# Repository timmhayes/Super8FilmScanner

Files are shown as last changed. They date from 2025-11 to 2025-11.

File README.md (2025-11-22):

# 3D printed Super 8 Film Scanner (Pi 5 / Ender 3 Fork)

> **NOTE:** This is a forked version of the excellent repo provided by Stuart Pittaway at [stuartpittaway/Super8FilmScanner](https://github.com/stuartpittaway/Super8FilmScanner). 
>
> I initially planned to make a few minor changes and update his repo via a pull request, but I've completely rewritten much of the code and I'm not sure that is possible now. In addition, many of the changes were made quickly with LLM coding tools and the code needs additional testing. 

**Substantial changes in this fork:**
1.  **Raspberry Pi 5 Support:** Updated to run on [Raspberry Pi 5](https://www.raspberrypi.com/products/raspberry-pi-5/) using the latest Pi OS (Bookworm/Trixie). The code now supports `picamera2` rather than relying on the deprecated `picamera`.
2.  **Machine Learning Alignment:** Improved sprocket alignment using a custom-trained [YOLO](https://docs.ultralytics.com/) machine learning model for object detection. (Moved to a separate repo).
3.  **Ender 3 Hardware:** Documented how an old [Ender 3](https://www.creality.com/products/ender-3-3d-printer) can be used to provide most of the moving parts. My build was created using an Ender 3 Pro with an updated [Silent Board](https://www.creality3dofficial.com/products/creality-silent-mainboard-v4-2-7). If you don't have one handy, a cheap secondhand model provides the motherboard, stepper motors, a control panel (not needed, but useable here), and some T-slotted rail to use on other projects.

---

# Project Overview

The code and scanner were created quickly to achieve the job of scanning a handful of Super 8 reels at an acceptable quality. The code is unlikely to run straight out of the box on your computer/system; it will need minor amendments to folder names/paths etc.

## Items needed for this project
* [Raspberry Pi 4](https://www.raspberrypi.com/products/raspberry-pi-4-model-b/) or [Raspberry Pi 5](https://www.raspberrypi.com/products/raspberry-pi-5/)
* [Pi Advanced 12megapixel Camera](https://www.raspberrypi.com/products/raspberry-pi-high-quality-camera/)
* [Microscope lens for the Raspberry Pi High Quality Camera - 0.12-1.8x](https://shop.pimoroni.com/products/microscope-lens-0-12-1-8x)
* 3D printed frame (files in this repository). The FreeCAD files are from the original project. STL files have neem added for convenience. A simple manual film rewinder is also included, but to complete the build you'll need to mount it on some T-slot rail and add some V-slot roller wheels for bearings. Both of these can can be pulled from an Ender 3.
* Two small depth stepper motors (NEMA 17 style - can be pulled from an old Ender 3)
* RAMPS style motherboard for controlling the stepper motors and running [MARLIN](https://github.com/MarlinFirmware/Marlin) (can be pulled from an old Ender 3)
* Two stepper drivers (e.g., A4988) - **Not required** if using an Ender 3 motherboard, as the drivers are soldered onto the board.
* ~5000K "cool white" MR16 style LED light bulb (5 Watt). A [base socket](https://www.amazon.com/dp/B073FFBSJM) is also helpful. I used a 12V version and needed a [buck converter](https://www.amazon.com/dp/B076H3XHXP) to step the voltage down from the 24V Ender 3 power supply.
* A small spring. One from [this assortment](https://www.amazon.com/dp/B0F9PZ5QHL) will work.
* A rubber gasket to fit over the stepper motor gear to make contact with the film. One of these [rubber grommets](https://www.amazon.com/dp/B07YXXYY7R) worked, but wasn't perfect and needed modification.
* 24V Power supply (an old Ender 3 PSU will do)
* MicroSD card
* Various M3 screws (like [these](https://www.amazon.com/dp/B07VRC5RJ8)).

# YouTube Video (Original Project)

See Stuart Pittaway's video on how to use and build the *original* device. 
**Note:** The physical build in this fork differs (using Ender 3 parts), but the general concept remains the same.

https://youtu.be/rd1Xu6e6nrw

# Setup

This is a rough setup description and some steps might be missing, but here is what's necessary:

## Step 1 - Flash Marlin to the mainboard
If needed, flash your mainboard with the Marlin Firmware. You can find the latest release [here](https://marlinfw.org/meta/download/). Open Arduino IDE, make the required changes (for your mainboard), connect the Mainboard via USB and upload the firmware.

**Note:** If your motherboard was pulled from an Ender 3, this step is likely unnecessary as it should already be running Marlin.

## Step 2 - Install the Raspberry Pi OS on the Raspberry Pi
Install the Raspberry Pi Imager, which you can find [here](https://www.raspberrypi.com/software/).

Plug the microSD card into your computer and choose to install the **Raspberry Pi OS (64-bit)** (Bookworm or later) in the imager software. Click the gear icon to open the advanced settings. Choose a hostname (e.g., "scanner"), add a username/password, activate SSH under "services", and add your Wifi settings.

## Step 3 - Wiring
Assemble the scanner according to the 3D files.

Mainboard
*Makerbase MKS 3D Printer Control Board*

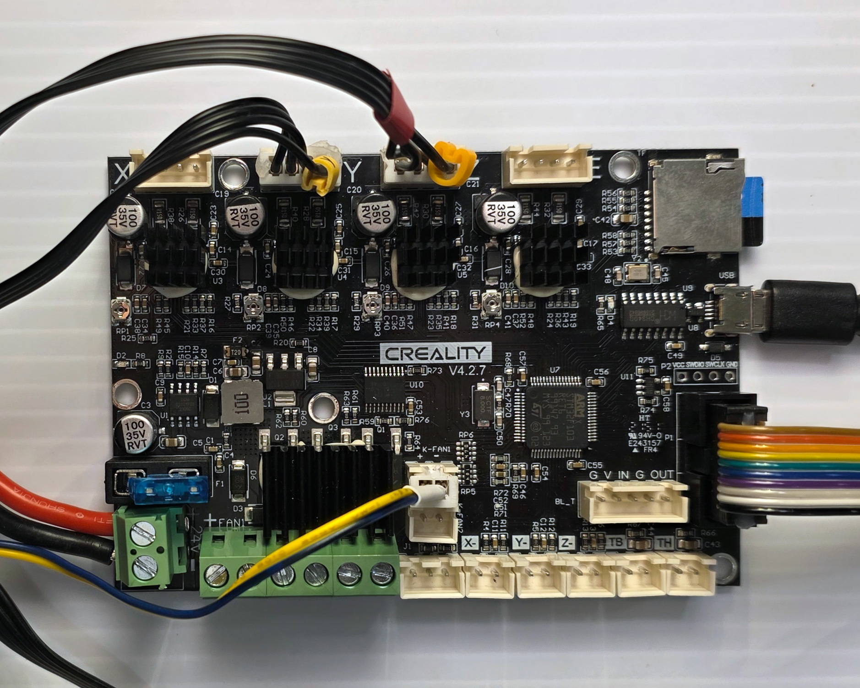
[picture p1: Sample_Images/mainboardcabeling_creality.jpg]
Creality Ender 3 Silent Motherboard

*Creality Ender 3 Silent Motherboard*

1.  Plug the stepper drivers into the mainboard's Y and Z axis (if not integrated), then plug in the stepper motors. 
2.  Consider adding a heatsink to the Y-axis stepper driver, as it is used the most. 
    *   *Tip:* If the Y-Axis stepper from the Ender 3 runs in the wrong direction, you may need to reverse the plug orientation or configure this in Marlin.
3.  Slot the Raspberry Pi HQ camera ribbon cable into the Raspberry Pi and lock it in place.
4.  Plug the LED wires into the fan header.
5.  Connect the power supply to the mainboard via the two cables. **Ensure the power supply is disconnected from the wall while wiring.**
6.  *(Optional)* Connect the Ender 3 control panel. This is not needed but may help with troubleshooting.(See the rainbow colored cable to the right above.)
7.  Connect the mainboard to the Raspberry Pi via USB.

## Step 4 - Connecting to the Raspberry Pi
If you don't plan to use the scanner with a dedicated monitor, keyboard, and mouse, you must connect via Terminal and VNC.

1.  Turn on the Raspberry Pi and the PSU.
2.  Use SSH to connect to `<username>@scanner.local`.
3.  Enable VNC on the Pi:
    1. Run the command: `sudo raspi-config`
    2. Navigate to `Interface Options` (option 5).
    3. Select `VNC` (option P3).
    4. Choose `Yes` to enable VNC.
    5. Exit raspi-config. RealVNC Server will start automatically on boot.
4. Download and install a VNC client on the computer you will connect to your Raspberry Pi. (e.g. [RealVNC Viewer](https://www.realvnc.com/en/connect/download/viewer/))

## Step 5 - Install dependencies
The software relies on `picamera2`, `pyserial`, and `opencv`. The first two should be available in the default system build, so start by installing OpenCV:

```bash
sudo apt update
sudo apt upgrade
sudo apt install python3-opencv
```

If you are running an older version of the Raspberry Pi OS and need the additional libraries, install them:
```bash
sudo apt install python3-picamera2 python3-serial
```

The following is not required, but you might find the [Visual Studio Code](https://code.visualstudio.com/) IDE helpful:
```bash
sudo apt install code
```

# Scanning Process

## Step 1 - Capture full frame masters

On the Raspberry Pi, use the python code in `RasPi_Camera_Super8Scanner.py` to capture individual frames to PNG files.

**Configuration:**
The scanner settings (frame dimensions, feed rates, exposure defaults) are located in the `ScannerConfig` class at the top of `RasPi_Camera_Super8Scanner.py`. Edit these values to match your specific hardware setup.

**Running the Scanner:**
```bash
python3 RasPi_Camera_Super8Scanner.py
```

**Controls:**
- **Startup Alignment:** Use the arrow keys to align the film. Press `SPACE` to start scanning.
- **Scanning:** The scanner will automatically advance frames.
- **Manual Mode:** Press `m` to enter manual mode if things go wrong.
    - `f`/`b`: Forward/Backward nudge
    - `[`/`]`: Adjust threshold. Hold Shift to advance 10 steps at a time.
    - `SPACE`: Resume auto-scanning

This will generate a large number of files (3000+) of significant file size 2+MByte each.  Camera captures approximately 3megapixel images.

The images captured will look like this (only higher resolution). Notice you can see the sprocket hole and the black border on the right of the image.
Full frame sample image

## Step 2 - Alignment
The alignment process is computationally intensive and runs much faster on a dedicated machine, particularly one with a dedicated GPU and NVMe drive. The code for doing this, which was once part of this repo, has been completely refactored and split off into a separate repo. Please see the following repo for alignment code:

[8mm Film Frame Processor with YOLO Detection](https://github.com/timmhayes/8mm-film-frame-processor)

**[Link TBD]**

## Configuration
Advanced settings can be found in the `ScannerConfig` class within `RasPi_Camera_Super8Scanner.py`. Key settings include:

| Setting | Description | Default |
| :--- | :--- | :--- |
| `CAMERA_EXPOSURE` | List of EV values. Add multiple (e.g., `[-2.0, 0.0, 2.0]`) for HDR bracketing. | `[-8.0]` |
| `FRAME_SPACING` | Millimeters of film to advance per frame. Tweak this if you find your scanning process moving back and forth frequently to correct frame drift. This can slow down the scan significantly. | `16.0` |
| `NUDGE_FEED_RATE` | Speed of the motor during manual adjustments. | `1000` |

## Output Directory Structure
Images are saved to the `Capture` folder in the current directory.
*   `./Capture/Capture-8.0/`: Contains the raw PNG images for the -8.0 EV exposure.
*   If you configure multiple exposures, additional folders (e.g., `Capture-2.0`) will be created.

## Code Overview
*   `RasPi_Camera_Super8Scanner.py`: Main application loop, state management, and UI.
*   `camera_control.py`: Wrapper for `picamera2` handling hardware interactions.
*   `marlin_control.py`: Handles G-code serial communication with the stepper board.
*   `image_processing.py`: OpenCV logic for sprocket detection and image analysis.

## 3D Print Files
The `3d-Print-Files` folder contains FreeCAD (`.FCStd`) source files. You will need [FreeCAD](https://www.freecad.org/) to view these or export them as STL files for printing.

## Troubleshooting
*   **Serial Permission Error:** If you get a permission error accessing `/dev/ttyUSB0`, run `sudo usermod -a -G dialout $USER` and reboot.
*   **Camera Errors:** Ensure the camera works outside the script by running `libcamera-hello` in a terminal.
*   **Sprocket Detection Fails:** If the scanner keeps stopping, try adjusting the backlight brightness or use the `[` and `]` keys during the scan to adjust the detection threshold.
*   **Constant Adjustments During Scan:** The scanning process should continue advancing the film with minimal adjustment. If you notice it frequently pausing for micro-adjustments, adjust the `FRAME_SPACING` setting to better work with your setup.

## License
This project is licensed under the GNU General Public License v3.0. See the `LICENSE` file for details.

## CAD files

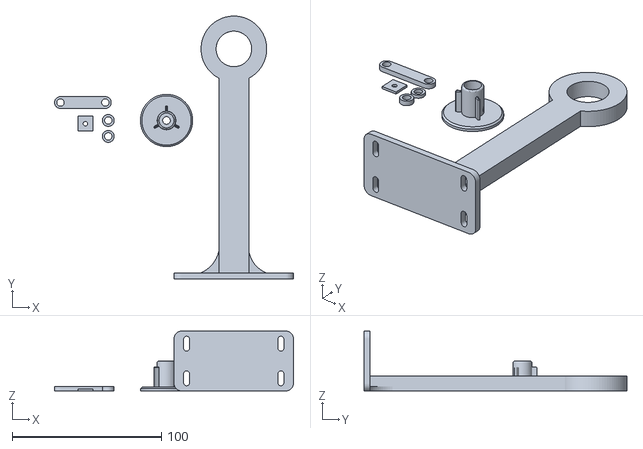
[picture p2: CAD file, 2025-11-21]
3d-Print-Files/Manual Film Rewinder.stl
160.0 x 176.0 x 40.0

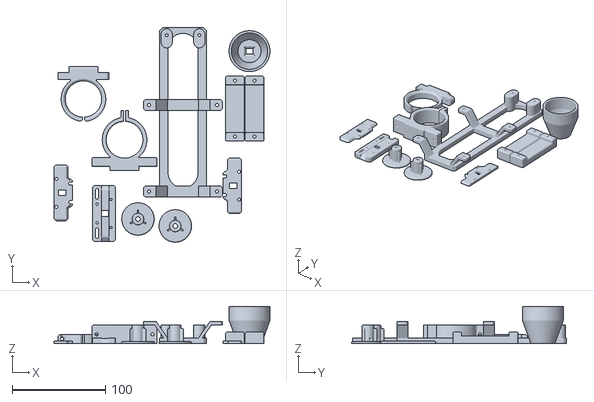
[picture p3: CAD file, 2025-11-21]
3d-Print-Files/OtherParts.stl
232.0 x 230.5 x 40.0

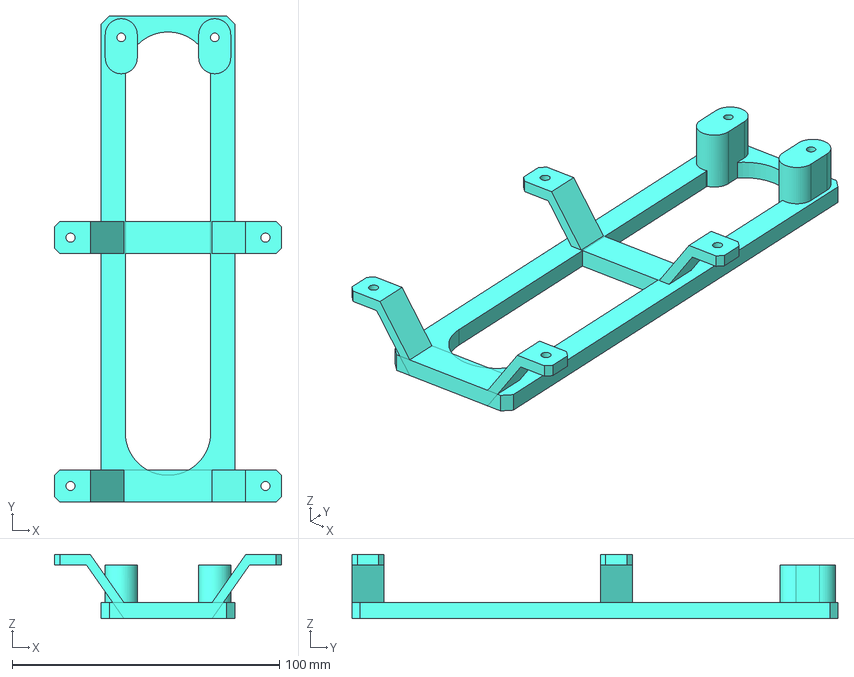
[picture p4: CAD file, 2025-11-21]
3d-Print-Files/CameraMount-RaspPiAdvanced.FCStd
85.0 x 182.0 x 24.0 mm

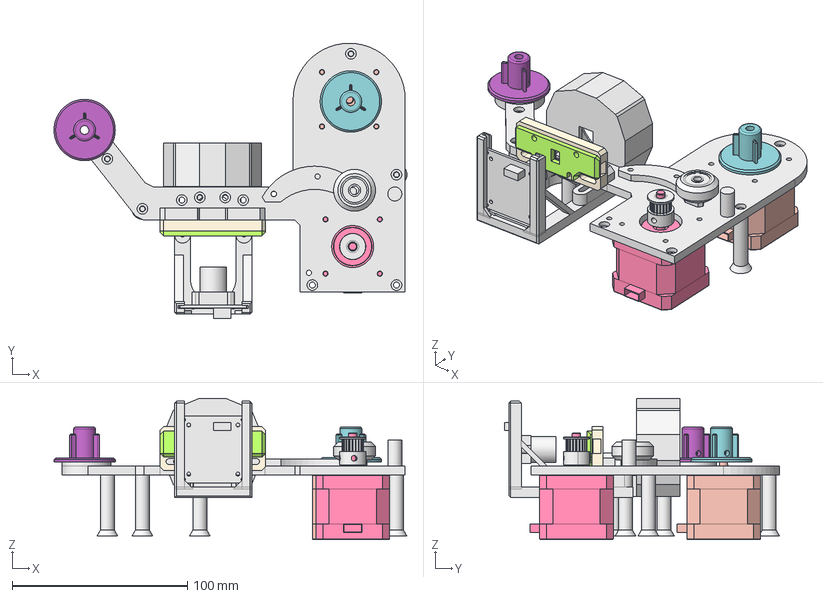
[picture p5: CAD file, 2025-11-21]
3d-Print-Files/Assemby.FCStd
201.5 x 157.2 x 80.6 mm
BackPlate_Body-Arm_001
BackPlate_Body-CameraMount_001
BackPlate_Body-Frame_001
BackPlate_Body-Turret_001
BackPlate_Body-Turret_002
BackPlate_Body-Turret_003
Super8FilmScanner_Body-Gate-Back_001
Super8FilmScanner_Body-Gate-Front_001
Super8FilmScanner_Body-TapeWheel_001
Super8FilmScanner_Body-TapeWheel_002
BackPlate_Body-Turret_004
BackPlate_Body-Turret_007
BackPlate_Body-LampMount_001
OTS-0002-00_usb-webcam_Body_001
OTS-0017_GT2-20-tooth-pulley1_Gates_2GT_20T_Toothed_Pulley_001
OTS-0012_nema17-stepper1_Nema 17 42A02C v2_001
OTS-0012_nema17-stepper1_Nema 17 42A02C v2_002
OTS-0011_v-slot-roller1_Fusion_001

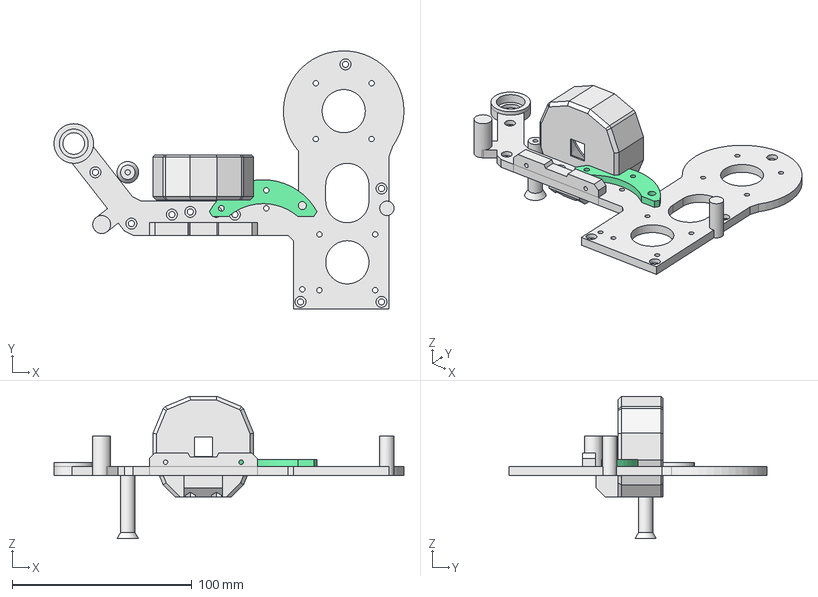
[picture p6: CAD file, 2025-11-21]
3d-Print-Files/BackPlate.FCStd
194.5 x 143.5 x 79.1 mm
Body-Frame
Body-Arm
Body-Turret
Body-LampMount

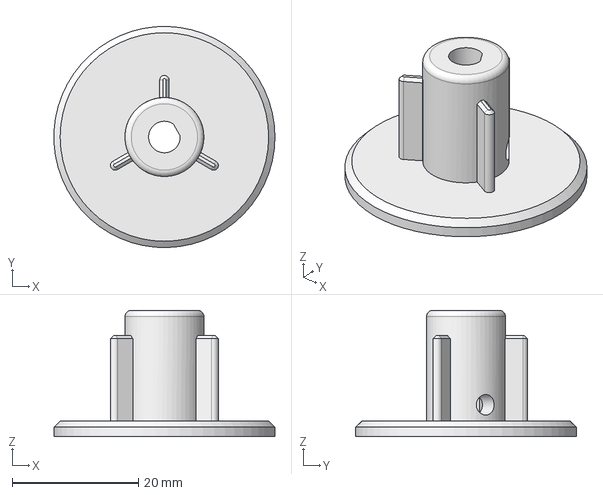
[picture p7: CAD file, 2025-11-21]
3d-Print-Files/Super8FilmScanner.FCStd
35.0 x 35.0 x 20.0 mm

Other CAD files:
3d-Print-Files/BackPlate.stl

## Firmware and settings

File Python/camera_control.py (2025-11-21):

from __future__ import annotations

from typing import Optional, Tuple
import time
import logging

import cv2 as cv
from picamera2 import Picamera2


logger = logging.getLogger(__name__)


class CameraController:
    """Encapsulates Picamera2 configuration and capture helpers.

    Responsibilities:
    - Configure preview/high-res pipelines
    - Start/stop camera lifecycle
    - Stable exposure and AWB helpers (auto once, then lock)
    - Provide frames in BGR for OpenCV
    """

    def __init__(self) -> None:
        self.camera: Optional[Picamera2] = None
        self.shutter_speed: int = 1000
        self.iso: int = 100
        self.locked_awb_gains: Optional[Tuple[float, float]] = None
        self.swap_rb: bool = False

    # ---------- Lifecycle ----------
    def configure_high_res_camera(self) -> Tuple[int, int]:
        """Configure the camera for high-resolution video capture and return PixelArraySize (w, h).
        Reuses an existing Picamera2 instance when possible to avoid device-busy errors.
        """
        if self.camera is None:
            logger.info("Configuring high res camera settings (new instance)")
            self.camera = Picamera2()
        else:
            logger.info("Reconfiguring camera to high res settings")
            if self.camera.started:
                self.camera.stop()
        config = self.camera.create_video_configuration(
            main={"size": (2028, 1520), "format": "RGB888"}
        )
        self.camera.configure(config)
        # Disable automatic algorithms by default; we'll run them manually once
        self.camera.set_controls({
            "AeEnable": False,
            "AwbEnable": False,
        })
        return self._pixel_array_size()

    def configure_low_res_camera(self) -> Tuple[int, int]:
        """Configure the camera for low-resolution preview and return PixelArraySize (w, h).
        Reuses an existing Picamera2 instance when possible to avoid device-busy errors.
        """
        if self.camera is None:
            self.camera = Picamera2()
        else:
            if self.camera.started:
                self.camera.stop()
        config = self.camera.create_preview_configuration(main={"size": (640, 480), "format": "RGB888"})
        self.camera.configure(config)
        # Keep AE/AWB disabled by default; caller can perform auto once then lock
        self.camera.set_controls({
            "AeEnable": False,
            "AwbEnable": False,
        })
        return self._pixel_array_size()

    def start(self) -> None:
        assert self.camera is not None, "Camera not configured"
        if not self.camera.started:
            self.camera.start()

    def stop_and_close(self) -> None:
        if self.camera is not None:
            if self.camera.started:
                self.camera.stop()
            self.camera.close()
            self.camera = None

    def _pixel_array_size(self) -> Tuple[int, int]:
        assert self.camera is not None
        pas = self.camera.camera_properties["PixelArraySize"]
        # Picamera2 returns (width, height)
        return int(pas[0]), int(pas[1])

    # ---------- Capture ----------
    def capture_bgr(self, stream: str = "main"):
        """Capture a frame and return an image suitable for OpenCV (BGR).
        Assumes RGB888 stream; converts RGB->BGR. Handles RGBA->BGR if needed.
        """
        assert self.camera is not None, "Camera not configured"
        img = self.camera.capture_array(stream)
        if len(img.shape) == 3 and img.shape[2] == 4:
            # Convert RGBA to BGR
            try:
                bgr = cv.cvtColor(img, cv.COLOR_RGBA2BGR)
            except Exception:
                # Fallback channel reorder if cvtColor not available
                bgr = img[:, :, 2::-1]
            return bgr[:, :, ::-1] if self.swap_rb else bgr
        if len(img.shape) == 3 and img.shape[2] == 3:
            # Convert RGB888 to BGR for OpenCV
            bgr = cv.cvtColor(img, cv.COLOR_RGB2BGR)
            return bgr[:, :, ::-1] if self.swap_rb else bgr
        return img

    # ---------- Controls ----------
    def auto_shutter_speed(self) -> Tuple[int, float]:
        """Temporarily enable AE to get sane ExposureTime and AnalogueGain, then disable AE again."""
        assert self.camera is not None, "Camera not configured"
        self.camera.set_controls({"AeEnable": True})
        time.sleep(2)
        metadata = self.camera.capture_metadata()
        shutter_speed = int(metadata["ExposureTime"])  # us
        analogue_gain = float(metadata["AnalogueGain"])  # ~ISO/100
        self.camera.set_controls({"AeEnable": False})
        logger.info("Auto exposure settled: shutter=%s us, analogue_gain=%.2f", shutter_speed, analogue_gain)
        return shutter_speed, analogue_gain

    def set_exposure(self, shutter_speed: int, iso: int) -> None:
        """Disable AE and set ExposureTime + AnalogueGain derived from ISO.
        Note: ISO is approximated as analogue_gain = ISO/100.
        """
        assert self.camera is not None, "Camera not configured"
        self.shutter_speed = int(shutter_speed)
        self.iso = int(iso)
        analogue_gain = self.iso / 100.0
        self.camera.set_controls({
            "AeEnable": False,
            "ExposureTime": self.shutter_speed,
            "AnalogueGain": analogue_gain,
        })
        time.sleep(0.5)
        if self.camera.started:
            md = self.camera.capture_metadata()
            logger.info("Exposure set: iso=%s, shutter=%s us (md ExposureTime=%s)", self.iso, self.shutter_speed, md.get("ExposureTime"))

    def auto_white_balance(self, newgain: Optional[Tuple[float, float]] = None) -> Tuple[float, float]:
        """Run AWB briefly, lock gains, and return them. If newgain provided, apply and lock it."""
        assert self.camera is not None, "Camera not configured"
        if newgain is None:
            self.camera.set_controls({"AwbEnable": True})
            time.sleep(2)
            md = self.camera.capture_metadata()
            gains = tuple(md["ColourGains"])  # type: ignore
            self.camera.set_controls({"AwbEnable": False, "ColourGains": gains})
        else:
            gains = (float(newgain[0]), float(newgain[1]))
            self.camera.set_controls({"AwbEnable": False, "ColourGains": gains})
        self.locked_awb_gains = (float(gains[0]), float(gains[1]))
        logger.info("AWB locked with gains: %s", self.locked_awb_gains)
        return self.locked_awb_gains

    # ---------- Misc ----------
    def toggle_swap_rb(self) -> None:
        self.swap_rb = not self.swap_rb

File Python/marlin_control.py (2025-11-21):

from __future__ import annotations

import logging
from datetime import datetime
import time
from typing import Iterable

import serial


logger = logging.getLogger(__name__)


class Marlin:
    """Thin wrapper around a Marlin-compatible serial connection and common commands."""

    def __init__(self, port: str = "/dev/ttyUSB0", baudrate: int = 115200, timeout: float = 5.0) -> None:
        self.port = port
        self.baudrate = baudrate
        self.timeout = timeout
        self.ser: serial.Serial | None = None

    # ---------- Lifecycle ----------
    def connect(self) -> None:
        self.ser = serial.Serial(
            port=self.port,
            baudrate=self.baudrate,
            bytesize=8,
            timeout=self.timeout,
            stopbits=serial.STOPBITS_ONE,
            parity=serial.PARITY_NONE,
        )
        # Drain initial chatter
        self._wait_for_reply(echo=False)
        # Initial setup
        self.send_multiple([
            "M502",
            "G21",
            "M211 S0",
            "G90",
            "G92 X0 Y0 Z0",
            "M201 Y0",
            "M18 S15",
            "M203 X1000.00 Y1000.00 Z5000.00",
        ])
        self.set_light(255)
        self.send("M92 Y10 Z8.888888")  # steps per unit
        self.send("M400")  # wait complete

    def disconnect(self) -> None:
        if self.ser is None:
            return
        self.set_light(0)
        self.send_multiple(["M84"])  # steppers off
        self.ser.close()
        self.ser = None

    # ---------- Commands ----------
    def send(self, cmd: str) -> None:
        assert self.ser is not None, "Serial not connected"
        logger.info("Sending GCODE %s", cmd)
        if not self.ser.isOpen():  # type: ignore[attr-defined]
            raise RuntimeError("Port closed")
        self.ser.flushInput()
        self.ser.flushOutput()
        self.ser.read_all()
        self.ser.write(cmd.encode("utf-8"))
        self.ser.write(b"\n")
        if not self._wait_for_reply():
            raise RuntimeError("Bad GCODE command or no valid reply from Marlin")

    def send_multiple(self, cmds: Iterable[str]) -> None:
        for c in cmds:
            self.send(c)

    def set_light(self, level: int = 255) -> None:
        if level > 0:
            self.send(f"M106 S{level}")
        else:
            self.send("M107")

    def move_film(self, y: float, feed_rate: int) -> None:
        self.send(f"G0 Y{y:.4f} F{feed_rate}")
        self.send("M400")

    def move_reel(self, z: float, feed_rate: int, wait_for_completion: bool = True) -> None:
        self.send(f"G0 Z{z:.4f} F{feed_rate}")
        if wait_for_completion:
            self.send("M400")

    # ---------- Internal ----------
    def _wait_for_reply(self, echo: bool = True) -> bool:
        assert self.ser is not None, "Serial not connected"
        tstart = datetime.now()
        while True:
            if self.ser.in_waiting > 0:  # type: ignore[attr-defined]
                serial_bytes = self.ser.readline()
                if echo and serial_bytes.startswith(b"echo:"):
                    logger.info("Marlin R: %s", serial_bytes.decode("ascii", errors="ignore").strip())
                if serial_bytes == b"ok\n":
                    return True
                # reset timeout window when receiving anything
                tstart = datetime.now()
            else:
                time.sleep(0.01)
                duration = (datetime.now() - tstart).total_seconds()
                if duration > 3:
                    return False

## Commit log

2025-11-21 Refactor for RPi 5 and split alignment code into separate repo
    [Assemby.FCStd, BackPlate.FCStd, CameraMount-RaspPiAdvanced.FCStd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]
2025-11-21 Update .gitignore and add ignored files
    [BackPlate.stl, Manual Film Rewinder.stl, OtherParts.stl]
